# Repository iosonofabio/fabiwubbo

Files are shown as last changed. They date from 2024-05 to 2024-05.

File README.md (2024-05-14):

A wireless 38 key keyboard: a variation of the [Wubbo](https://github.com/cacheworks/Wubbo).

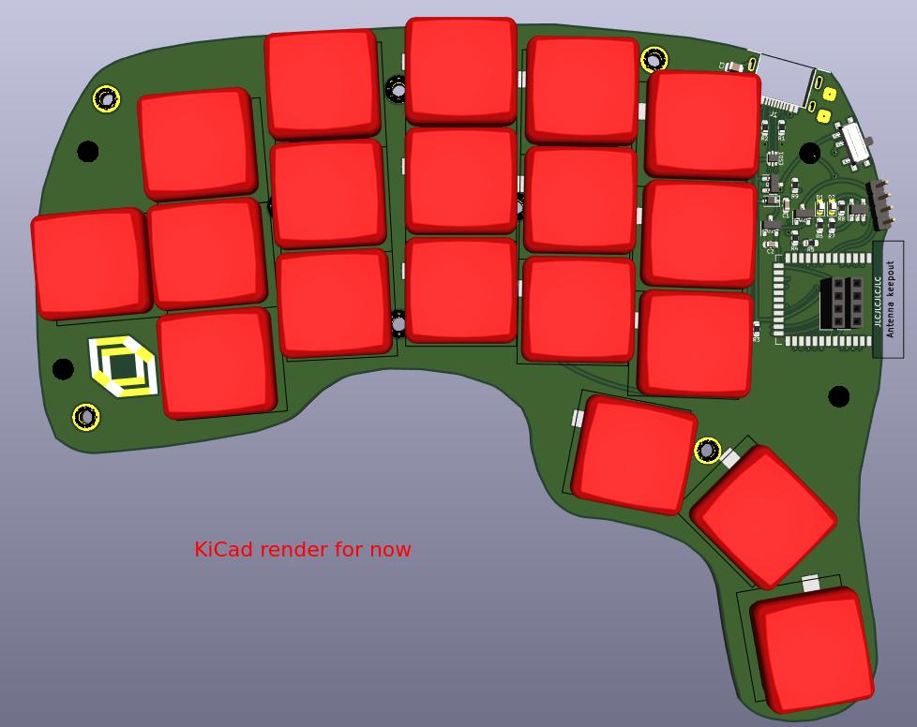
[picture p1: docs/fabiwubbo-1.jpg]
Wubbo


### [Interactive Bill of materials](https://iosonofabio.github.io/fabiwubbo/)

The following does not work for this keyboard yet... we'll get there someday hopefully.
### [Example ZMK config repo](https://github.com/mveerd/wubbo-zmk-config)

---
**NOTE:** The main PCB kicad files are where development is at now. No bottom or top plates and other things have been adapted yet.

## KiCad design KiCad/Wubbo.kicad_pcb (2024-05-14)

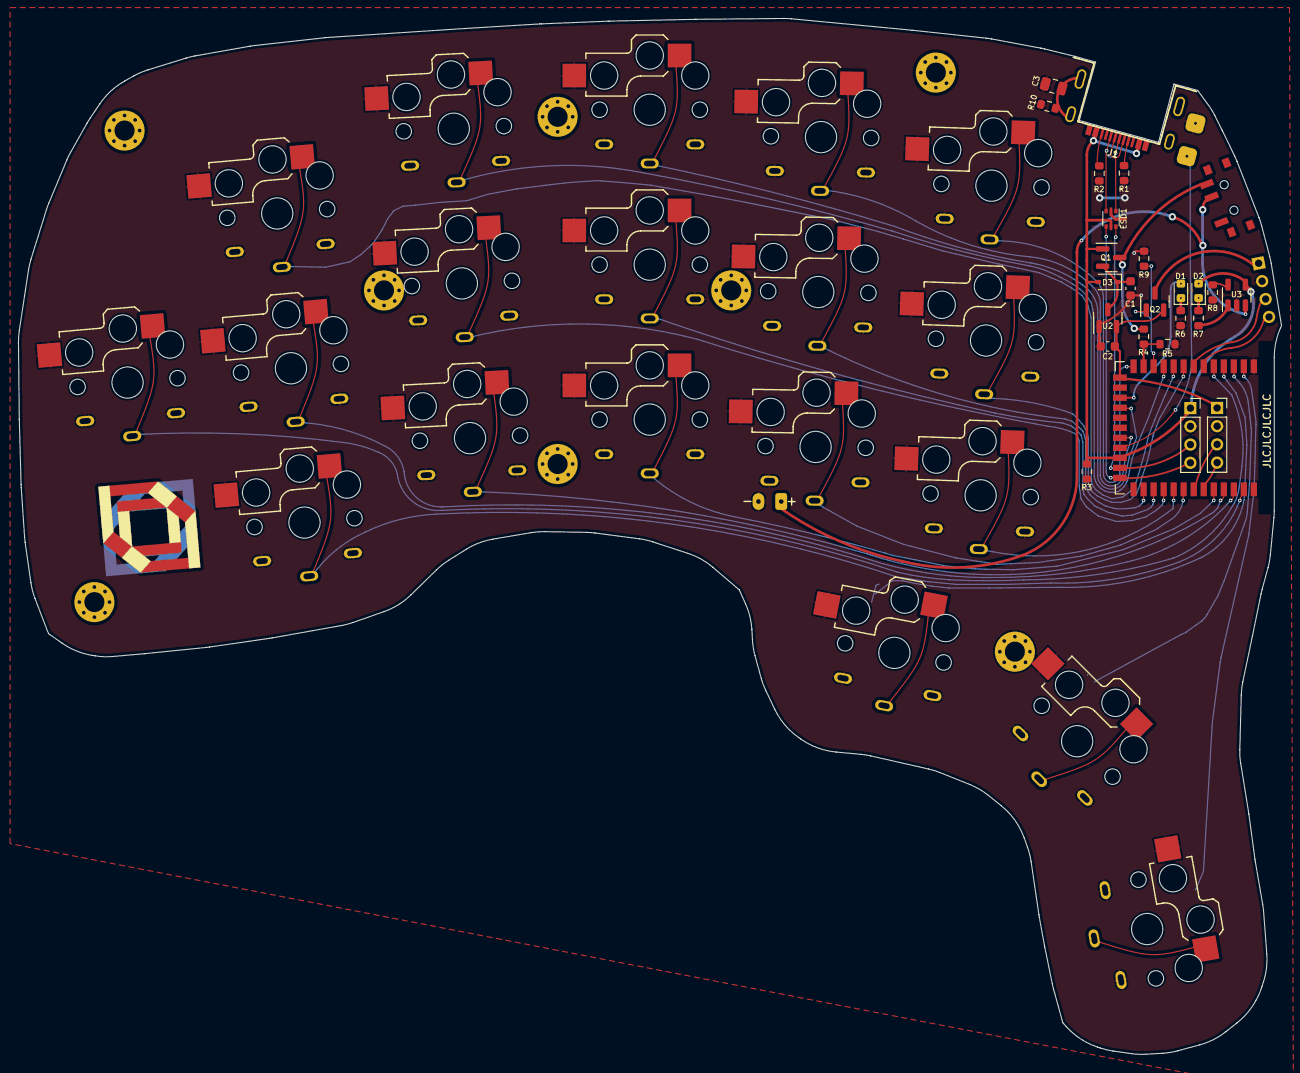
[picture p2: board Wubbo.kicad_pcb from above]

Board: 2 copper layers, 138.6 x 113.7 mm, 51 parts (1 on the bottom side), 41 nets.

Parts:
C1, C2: 1uF; C_0603_1608Metric
C3: 4.7n; C_0805_2012Metric
D1: Blue LED; LED_0603_1608Metric_shinethrough
D2: Red LED; LED_0603_1608Metric
D3: D_Schottky; D_SOD-323
ESD1: USBLC6-2P6; SOT-666
GR1, GR2: 9b7f651c-c6a4-4f53-b457-ec411c8fc700
J1: USB_C_Receptacle; USB-C-12-Pin-MidMount
J2: SWD; PinSocket_1x04_P2.00mm_Vertical
J3: USB; PinSocket_1x04_P2.00mm_Vertical
J4: JST-BATT; JST_PH_S2B-PH-K_1x02_P2.00mm_Horizontal
J5: USB; PinHeader_1x04_P2.00mm_Vertical
Q1, Q2: AO3407; SOT-23
R1, R2: 5.1K; R_0603_1608Metric
R3: 100K; R_0603_1608Metric
R4: 806/820k; R_0603_1608Metric
R5, R9: 2M; R_0603_1608Metric
R6, R7: 1K; R_0603_1608Metric
R8: 10K; R_0603_1608Metric
R10: 1M; R_0603_1608Metric
R_TACT1: SW_Push; 3-4-2_micro_tact_switch
SW1, SW2, SW3, SW4, SW5, SW6, SW7, SW8, SW9, SW10, SW11, SW12, SW13, SW14, SW15, SW16, SW17, SW18, SW19: Choc; PG13500-reversible
SW_POW1: SW_SPDT; SW_SPDT_PCM12
TENT1: Tenting Puck; Tenting_Puck
U1: nRF52840_holyiot_18010
U2: XC6206P LDO; SOT-23
U3: LTC4054ES5-4.2; TSOT-23-5

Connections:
+3V3: C2.1, J2.1, Q2.2 (S), U1.14 (VDD_nRF), U2.2 (VO)
+BATT: J4.1, SW_POW1.2 (B), U3.3 (BAT)
/BAT+_SWITCHED: Q1.3 (D), R4.1, SW_POW1.3 (C)
/Net-(U3-PROG): R8.2, U3.5 (PROG)
/V-IN: C1.1, D3.1 (K), Q1.2 (S), U2.3 (VI)
BLUE_LED: D1.2 (A), U1.16 (P1.09)
D+: ESD1.4 (I/O2), J3.4, U1.24 (D+)
D-: ESD1.6 (I/O1), J3.3, U1.23 (D-)
EXT_VCC: J5.1, Q2.3 (D)
Earth: C3.2, R10.2
GND: C1.2, C2.2, C3.1, ESD1.2 (GND), J2.2, J3.2, J4.2, J5.2, R1.2, R2.2, R3.2, R5.2, R6.2, R8.1, R9.2, R10.1, R_TACT1.2, SW1.2, SW2.2, SW3.2, SW4.2, SW5.2, SW6.2, SW7.2, SW8.2, SW9.2, SW10.2, SW11.2, SW12.2, SW13.2, SW14.2, SW15.2, SW16.2, SW17.2, SW18.2, SW19.2, U1.1 (GND), U1.25 (GND), U1.37 (GND), U2.1 (GND), U3.2 (GND)
unnamed: D1.1 (K), R6.1
unnamed: D2.1 (K), R7.1
unnamed: R7.2, U3.1 (~CHRG)
P0.02: J5.3, U1.7 (P0.02)
P0.03: J5.4, U1.6 (P0.03)
RESET: R_TACT1.1, U1.21 (P0.18/RESET)
SW1: SW1.1, U1.5 (P1.15)
SW2: SW2.1, U1.10 (P0.30)
SW3: SW3.1, U1.17 (P0.12)
SW4: SW4.1, U1.20 (P0.19)
SW5: SW5.1, U1.13 (P0.05)
SW6: SW6.1, U1.35 (P0.09)
SW7: SW7.1, U1.28 (P1.03)
SW8: SW8.1, U1.27 (P1.00)
SW9: SW9.1, U1.26 (P0.22)
SW10: SW10.1, U1.8 (P0.28)
SW11: SW11.1, U1.36 (P0.10)
SW12: SW12.1, U1.34 (P1.06)
SW13: SW13.1, U1.33 (P1.04)
SW14: SW14.1, U1.30 (P1.02)
SW15: SW15.1, U1.29 (P1.01)
SW16: SW16.1, U1.4 (P1.13)
SW17: SW17.1, U1.3 (P1.10)
SW18: SW18.1, U1.2 (P1.11)
SW19: SW19.1, U1.9 (P0.29)
SWDCLK: J2.3, U1.31 (SWDCLK)
SWDIO: J2.4, U1.32 (SWDIO)
VBUS: D2.2 (A), D3.2 (A), ESD1.5 (VBUS), J3.1, Q1.1 (G), R3.1, U1.22 (VBUS), U3.4 (VCC)
VCC_CONTROL: Q2.1 (G), R9.1, U1.11 (P0.31)
VSENSE: R4.2, R5.1, U1.12 (P0.04)

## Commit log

2024-05-14 Various modifications to make it 38 keys
    [Wubbo.kicad_pcb, Wubbo.kicad_sch]
2024-05-14 Bottom plate for new board shape
    [Bottom_Plate_fabiWubbo.kicad_pcb]
